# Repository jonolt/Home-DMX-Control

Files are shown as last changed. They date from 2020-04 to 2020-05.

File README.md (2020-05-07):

# Home DMC Controll - DONT USE!
**Dont use the data in this repository. Board and Software are not well designed.**

Improved Project was moved to 2 seperate repositories:
- [Home-DMX-Board](https://github.com/jonolt/Home-DMX-Board)
- [Home-DMX-Firmaware](https://github.com/jonolt/Home-DMX-Firmaware)

is a simple arduino based DMX controller to controll led lights installed in your home to be used with DMX controllers and relais.

## Idea

The selection for the lighting scene in daily use should be as simple as possible. Therefore exactly two push buttons are used to move up and down in a list of lighting scenes. Since I am not a fan of idle transformers, a conventional light switch is used in my application to switch the whole system on and off. In the same way a corresponding scene could be set.

The individual scenes should be adjustable directly on the controller without additional hardware. The input of the scenes works like on lighting control desks without motor faders via potentiometer and buttons. To make the firmware easy (without programmer and co) and maintainable by everyone, an Arduino was used, because it has a USB converter and the IDE is easy to use and install.

## End User Usage

### Everyay Usage

Use the two buttons (connecte do SW2 and SW3 on pcb) to change sceene, by going up and down an scene list.

### Configuration

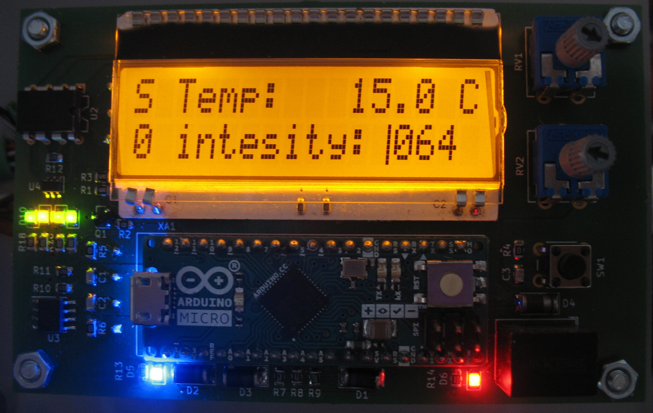
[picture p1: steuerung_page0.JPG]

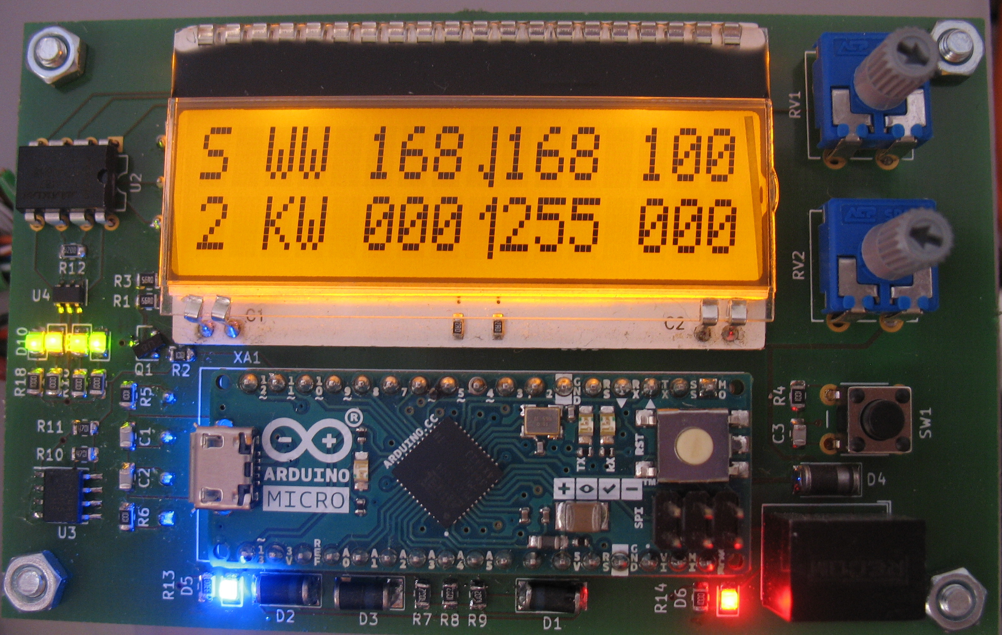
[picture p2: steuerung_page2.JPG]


Exact User Interface depends on the project specific arduino programm. The brigness values are set with two analog potis (one for each line). They work like in Ligthning Cosoles. A arrow up/down means the current poti value is below/above the software value. Chhanfing the poti value will not change the software value until bot values where matched once. This is shown when only a pipe is displayed.

#### Page 0

It is used to adjust the brightness of the display and to show the temperature measured by the I2C temperature sensor.

#### Page X (1, ..., 9)

Each page stores one light scene. In my project I have 3 zones of WW/CW LED stripes which should be switched independently. The zones are divided into columns. With SW1 a column can be selected and with RV1 and RV2 the brightness can be adjusted. To switch pages SW2 and SW3 are used which are not on the board. 

## Hard- and Software

### Hardware

Because I want to see if my hardware is running I have a power LED (D4) and a status LED (D5), which is switched on and off in my loop. This may cost an I/O pin, but you can always see if the firmware is running properly.

The MAX481 (U2) is a transceiver for RS-485 and RS-422 communication based on DMX. It uses the TX and RX pins of the arduino. For a visual control of the DMX communication 2x2 (overkill) leds are connected via buffer (U4).

The display is controlled serially via the library provided by the manufacturer.

Since only one interrupt is available when using IC2, all three switches are connected to it via diodes (D1, D2, D3) and the pressed switch is determined in the ISR. The switches are already hardware debaunced.

The I2C temperature sensor can be used for an emergency shutdown, or as I use it, just to see how warm it is in the chamber with the transformers (I trust the thermal protection of the power supplies).

### Software

The scenes and the current page and current column are stored in the EPPROM. Each page/scene has in the current implementation 10 8-bit registers to store DMX values. These can be accessed by adding the number of the register to the start address of the page, where the start address depends on the current page.

The Main Loop consists of 4 parts

1. Check whether a switch has been pressed and do according action
2. Check whether the potentiometer value has changed and whether the value must be adopted and update the display
3. Write DMX values
4. Toogle status LED

Code is more or less self explaining (sorry for the a bit cryptic math logic for pages). Be aware of the pointers in the trace method.

## Project Example

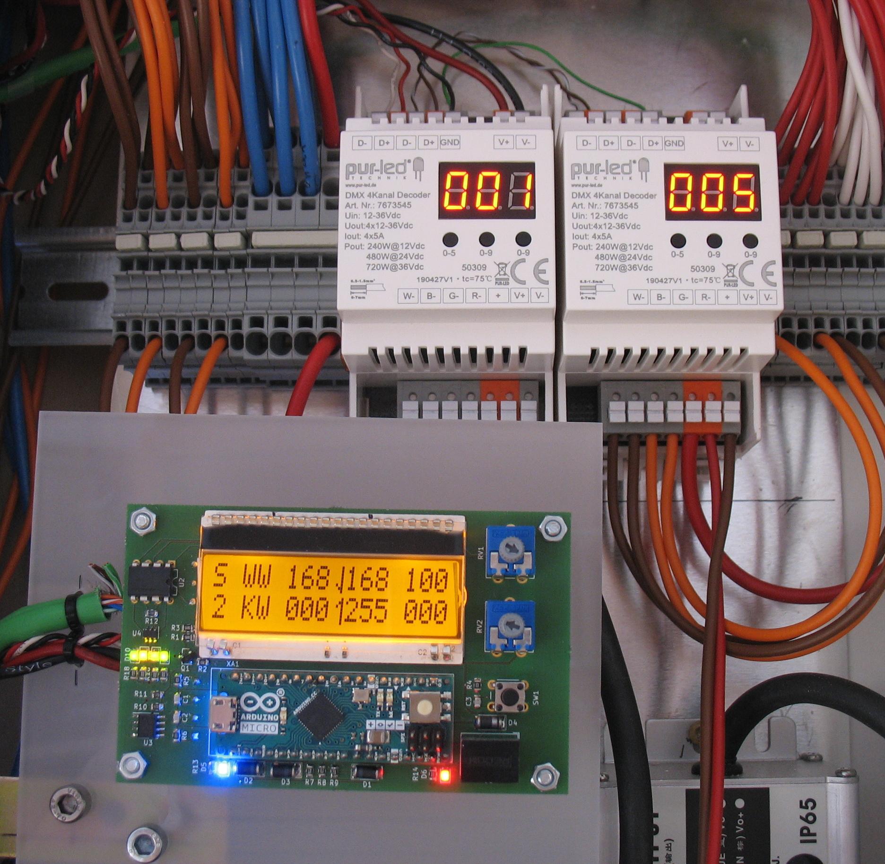
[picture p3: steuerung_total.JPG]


## Licence

See subfolders for indiviadual licences for each part of this project.

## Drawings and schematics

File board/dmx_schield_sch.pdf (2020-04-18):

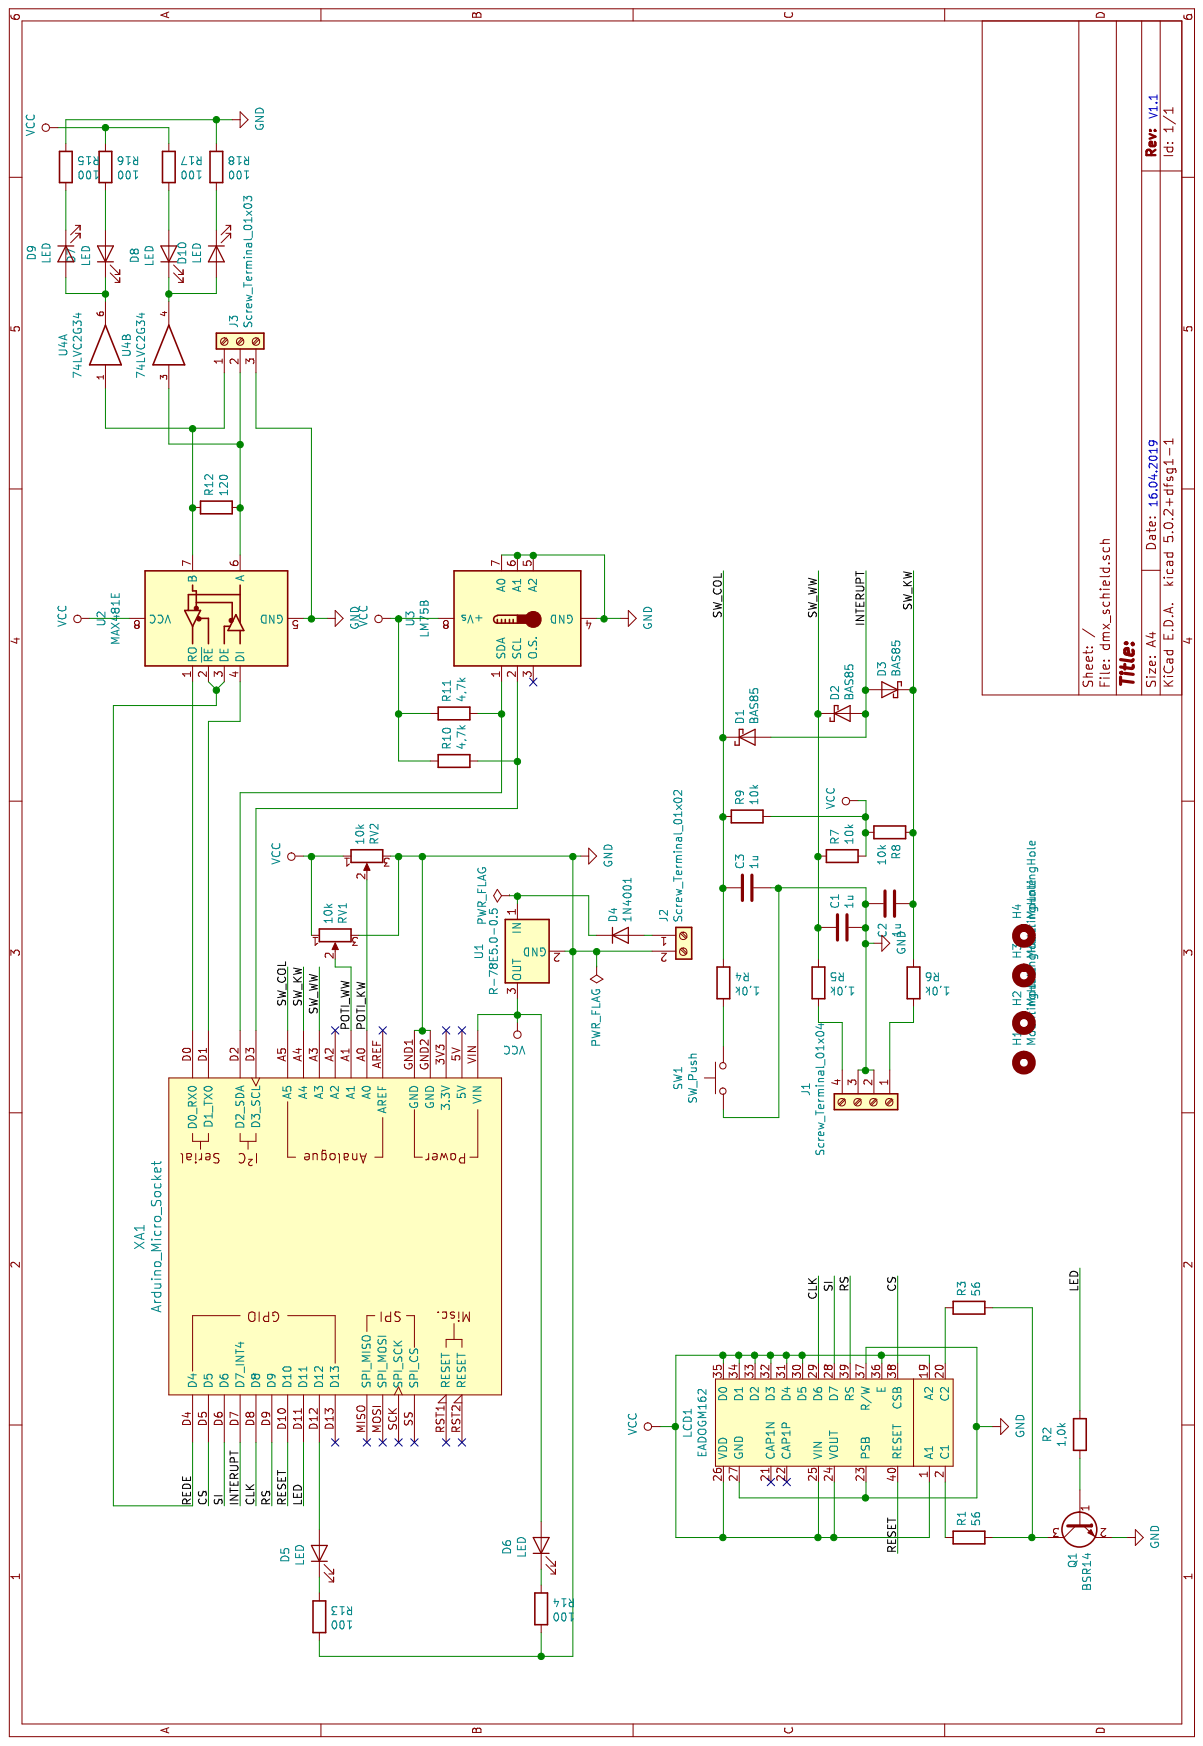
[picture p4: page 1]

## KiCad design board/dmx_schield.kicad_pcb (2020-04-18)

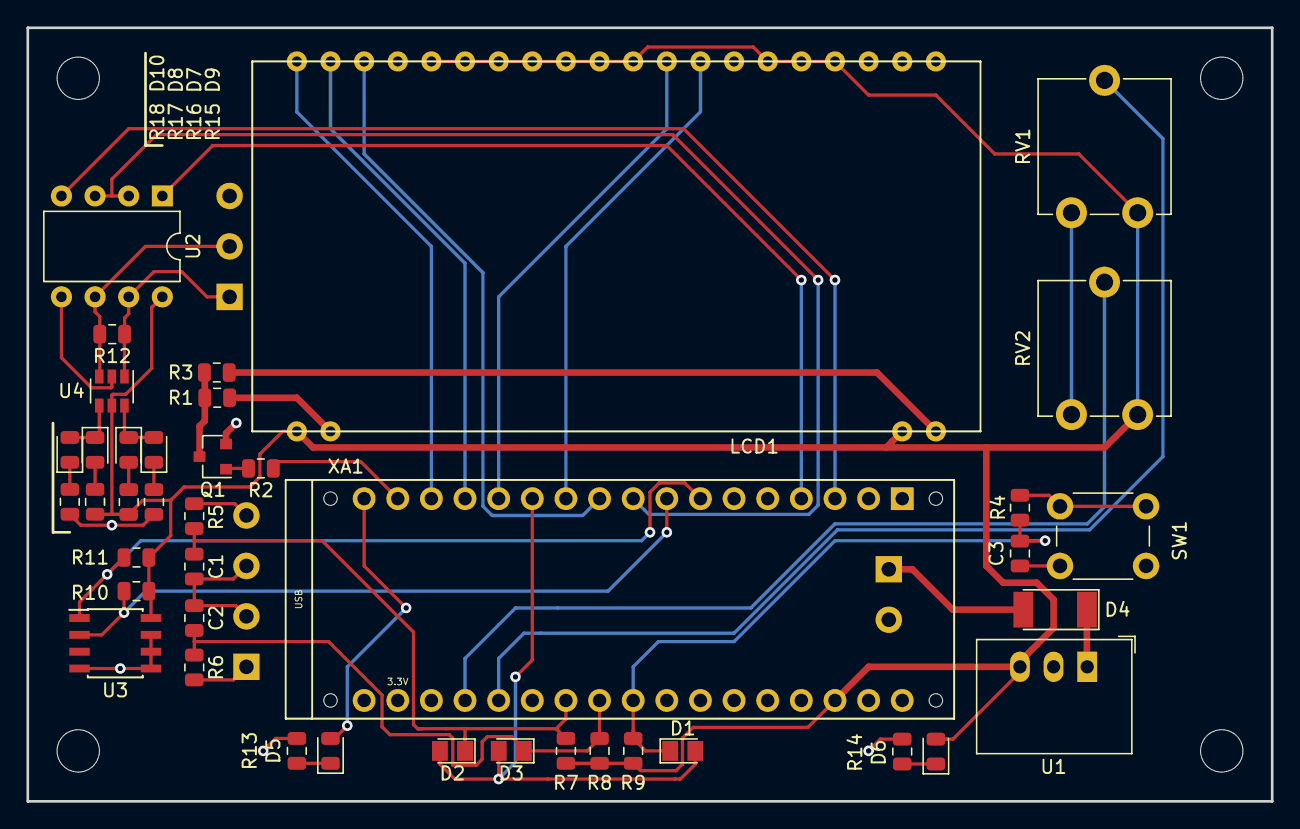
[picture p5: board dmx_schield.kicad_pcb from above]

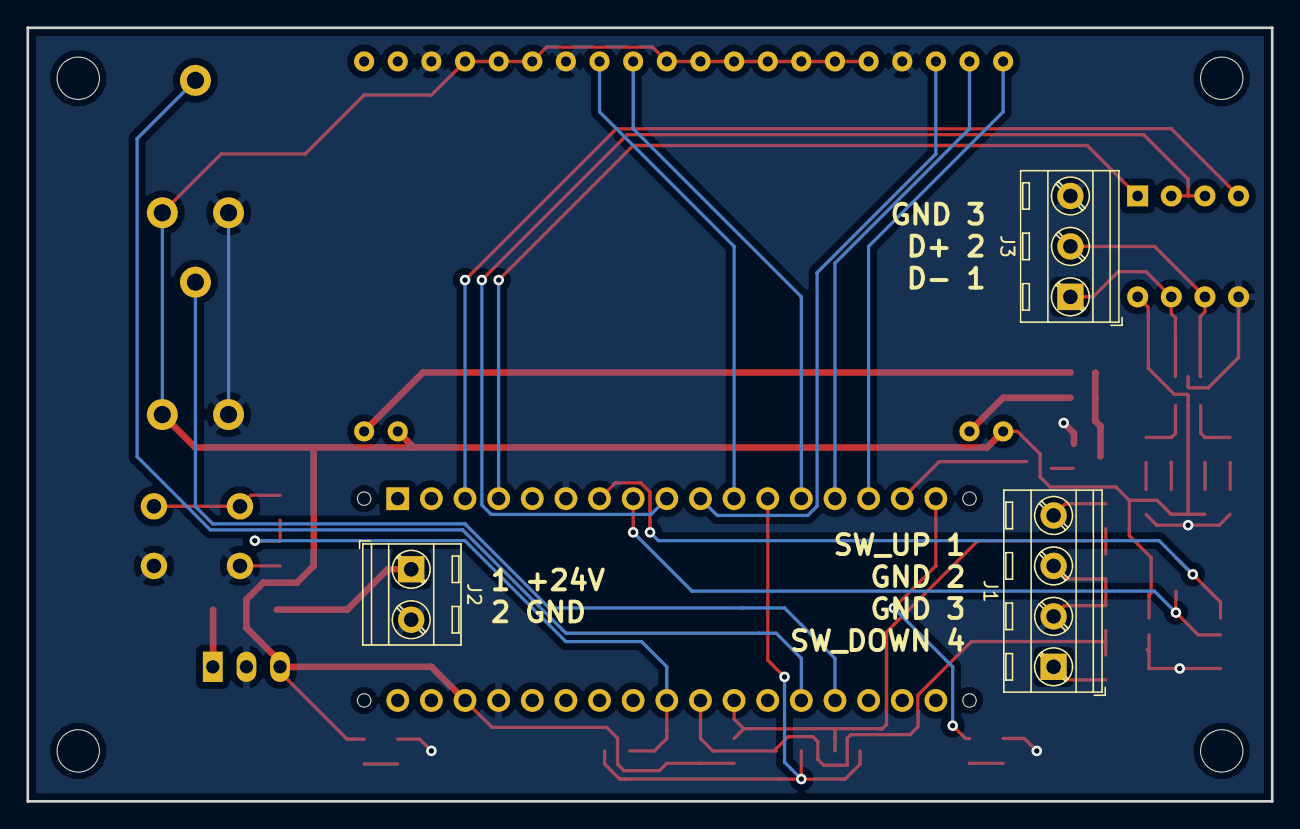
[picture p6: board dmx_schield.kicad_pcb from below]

Board: 2 copper layers, 94.0 x 58.4 mm, 48 parts (3 on the bottom side), 39 nets.

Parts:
C1, C2, C3: 1u; C_0805_2012Metric
D1, D2, D3: BAS85; D_MicroMELF
D4: 1N4001; D_MELF
D5, D6, D7, D8, D9, D10: LED; LED_0805_2012Metric
H1, H2, H3, H4: MountingHole; MountingHole_3.2mm_M3_DIN965
J1: Screw_Terminal_01x04; TerminalBlock_MetzConnect_Type086_RT03404HBLC_1x04_P3.81mm_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
J2: Screw_Terminal_01x02; TerminalBlock_MetzConnect_Type086_RT03402HBLC_1x02_P3.81mm_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
J3: Screw_Terminal_01x03; TerminalBlock_MetzConnect_Type086_RT03403HBLC_1x03_P3.81mm_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
LCD1: EADOGM162; EA DOGM 162
Q1: BSR14; SOT-23
R1, R3: 56; R_0805_2012Metric
R2, R4, R5, R6: 1,0k; R_0805_2012Metric
R7, R8, R9: 10k; R_0805_2012Metric
R10, R11: 4,7k; R_0805_2012Metric
R12: 120; R_0805_2012Metric
R13, R14, R15, R16, R17, R18: 100; R_0805_2012Metric
RV1, RV2: 10k; Potentiometer_ACP_CA9-V10_Vertical
SW1: SW_Push; SW_PUSH_6mm_H5mm
U1: R-78E5.0-0.5; Converter_DCDC_RECOM_R-78E-0.5_THT
U2: MAX481E; DIP-8_W7.62mm
U3: LM75B; SOIC-8_3.9x4.9mm_P1.27mm
U4: 74LVC2G34; SOT-23-6
XA1: Arduino_Micro_Socket

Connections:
/CLK: LCD1.29, XA1.D8
/CS: LCD1.38, XA1.D5
/INTERUPT: D1.2, D2.2, D3.2, XA1.D7
/LED: R2.1, XA1.D11
/POTI_KW: RV2.2, XA1.A0
/POTI_WW: RV1.2, XA1.A1
/REDE: U2.2, U2.3, XA1.D4
/RESET: LCD1.40, XA1.D10
/RS: LCD1.39, XA1.D9
/SI: LCD1.28, XA1.D6
/SW_COL: C3.1, D1.1, R4.1, R9.1, XA1.A5
/SW_KW: C2.2, D3.1, R6.1, R8.1, XA1.A4
/SW_WW: C1.1, D2.1, R5.1, R7.1, XA1.A3
GND: C1.2, C2.1, C3.2, J1.2, J1.3, J2.2, J3.3, LCD1.23, LCD1.27, LCD1.37, Q1.2, R13.2, R14.2, R15.1, R18.1, RV1.3, RV2.3, SW1.1, U1.2, U2.5, U3.4, U3.5, U3.6, U3.7, U4.2, XA1.GND1, XA1.GND2
unnamed: D4.1, U1.1
unnamed: D4.2, J2.1
unnamed: D5.1, R13.1
unnamed: D5.2, XA1.D12
unnamed: D6.1, R14.1
unnamed: D7.1, D9.2, U4.6
unnamed: D7.2, R16.2
unnamed: D8.2, R17.2
unnamed: D9.1, R15.2
unnamed: D10.1, R18.2
unnamed: D8.1, D10.2, U4.4
unnamed: J1.1, R6.2
unnamed: J1.4, R5.2
unnamed: J3.1, R12.1, U2.7, U4.1
unnamed: J3.2, R12.2, U2.6, U4.3
unnamed: LCD1.2, R1.1
unnamed: LCD1.20, R3.1
unnamed: Q1.1, R2.2
unnamed: Q1.3, R1.2, R3.2
unnamed: R4.2, SW1.2
unnamed: R10.2, U3.2, XA1.D3
unnamed: R11.2, U3.1, XA1.D2
unnamed: U2.1, XA1.D0
unnamed: U2.4, XA1.D1
VCC: D6.2, LCD1.1, LCD1.19, LCD1.24, LCD1.25, LCD1.26, LCD1.30, LCD1.31, LCD1.32, LCD1.33, LCD1.34, LCD1.35, LCD1.36, R7.2, R8.2, R9.2, R10.1, R11.1, R16.1, R17.1, RV1.1, RV2.1, U1.3, U2.8, U3.8, U4.5, XA1.VIN

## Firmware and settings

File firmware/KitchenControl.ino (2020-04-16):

/*
 * Copyright (C) 2019, 2020 Johannes N.
 * 
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
 * You should have received a copy of the GNU General Public License
 * along with this program.  If not, see <https://www.gnu.org/licenses/>.
 */

#include <Arduino.h>
#include <SPI.h>
#include <EEPROM.h>
#include <DMXSerial.h>
#include <Temperature_LM75_Derived.h>
#include "dogm_7036.h"

#define LM75_ADDRESS 0x48

#define PIN_BACKLIGHT 11
#define PIN_LED_STATUS 12
#define PIN_ARDUINO_LED 13
#define PIN_POTI_KW A0
#define PIN_POTI_WW A1
#define PIN_INTERUPT 7
#define PIN_SW_UP A3
#define PIN_SW_DOWN A4
#define PIN_SW_COL A5

#define PIN_R232_REDE 4

#define EPPROM_BACKLIGHT 1
#define EEPROM_PAGE 0
#define EPROME_COL 2


//Display
dogm_7036 DOG;
byte DOG_ARROW_POS[] = {5, 9, 13};
byte arrow_none[] = {0x01, 0x01, 0x01, 0x01, 0x01, 0x01, 0x01, 0x01};
byte arrow_up[] = {0x01, 0x03, 0x05, 0x01, 0x01, 0x01, 0x01, 0x01};
byte arrow_down[] = {0x01, 0x01, 0x01, 0x01, 0x01, 0x05, 0x03, 0x01};

//Aquire Value
bool trace_ww = false;
bool trace_kw = false;
bool trace_start = false;
volatile bool isr_triggered = false;
volatile bool isr_state_sw_up = true;
volatile bool isr_state_sw_down = true;
volatile bool isr_state_sw_col= true;


//Others
bool status_led = true;
Generic_LM75 temperature(LM75_ADDRESS);


//Function
void writeDMX();
void set_toogle_status_led();
void trace(byte addr, byte poti_val, bool trace);
void isr();
byte get_addr_start();
byte get_poti_ww_value();
byte get_poti_kw_value();
byte get_poti_value(int pin);
void set_backlight();


void setup() {

  //Setup Display
  DOG.initialize(5, 6, 8, 9, 10, 1, DOGM162); //byte p_cs, byte p_si, byte p_clk, byte p_rs, byte p_res, boolean sup_5V, byte lines
  DOG.displ_onoff(true);
  DOG.cursor_onoff(false);
  DOG.define_char(0, arrow_none);
  DOG.define_char(1, arrow_up);
  DOG.define_char(2, arrow_down);

  //Setup Pins
  pinMode(PIN_BACKLIGHT, OUTPUT);
  digitalWrite(PIN_BACKLIGHT, HIGH);
  pinMode(PIN_LED_STATUS, OUTPUT);
  digitalWrite(PIN_LED_STATUS, HIGH);
  pinMode(PIN_R232_REDE, OUTPUT);
  digitalWrite(PIN_R232_REDE, HIGH);
  pinMode(PIN_SW_COL, INPUT);
  pinMode(PIN_SW_UP, INPUT);
  pinMode(PIN_SW_DOWN, INPUT);
  pinMode(PIN_INTERUPT, INPUT);
  pinMode(PIN_INTERUPT, INPUT_PULLUP);
  attachInterrupt(digitalPinToInterrupt(PIN_INTERUPT), isr, FALLING);

  //Setup EPPROM
  if (EEPROM.read(EEPROM_PAGE) > 9) {
    EEPROM.write(EEPROM_PAGE, 0);
  }
  if (EEPROM.read(EPROME_COL) > 2) {
    EEPROM.write(EPROME_COL, 0);
  }
  EEPROM.write(100, 0);
  EEPROM.write(101, 0);
  EEPROM.write(102, 0);
  EEPROM.write(103, 0);
  EEPROM.write(104, 0);
  EEPROM.write(105, 0);

  //Setup Communiication (DMX, Serial)
  DMXSerial.init(DMXController);
  Wire.begin();

}


void loop() {
  if(isr_triggered){
    delay(50);
    handle_isr();
  } 
  set_backlight();
  if (EEPROM.read(EEPROM_PAGE) != 0) {
    digitalWrite(PIN_ARDUINO_LED, LOW);
    int addr = get_addr_start();
    String strW = "S WW";
    String strK = String(EEPROM.read(EEPROM_PAGE));
    strK.concat(" KW");
    for (int i = 0; i < 3; i++) {
      char buf[3];
      sprintf(buf, " %03d", EEPROM.read(addr + 2 * i));
      strW.concat(buf);
      sprintf(buf, " %03d", EEPROM.read(addr + 2 * i + 1));
      strK.concat(buf);
    }
    DOG.position(1, 1);
    DOG.string(strW.c_str());
    DOG.position(1, 2);
    DOG.string(strK.c_str());
    byte col = EEPROM.read(EPROME_COL);
    DOG.position(DOG_ARROW_POS[col], 1);
    trace(addr + 2 * col, get_poti_ww_value(), &trace_ww);
    DOG.position(DOG_ARROW_POS[col], 2);
    trace(addr + 2 * col + 1, get_poti_kw_value(), &trace_kw);
    delay(100);
  }
  else
  {
    digitalWrite(PIN_ARDUINO_LED, HIGH);
    DOG.position(1, 1);
    DOG.string("S Temp:        C");
    DOG.position(11, 1);
    DOG.string(String(temperature.readTemperatureC(), 1).c_str());
    DOG.position(1, 2);
    DOG.string("0 intesity:");
    char buf[3];
    sprintf(buf, " %03d   ", EEPROM.read(EPPROM_BACKLIGHT));
    DOG.string(buf);
    DOG.position(12, 2);
    trace(EPPROM_BACKLIGHT, get_poti_kw_value(), &trace_start);
    delay(50);
  }
  writeDMX();
  set_toogle_status_led();
}

void writeDMX() {
  //send values from EPPROM to dimmer
  int addr = get_addr_start();
  //RegalUnten
  DMXSerial.write(1, EEPROM.read(addr + 0));
  DMXSerial.write(2, EEPROM.read(addr + 1));
  //RegalOben
  DMXSerial.write(3, EEPROM.read(addr + 2));
  DMXSerial.write(4, EEPROM.read(addr + 3));
  //Glasswand
  DMXSerial.write(5, EEPROM.read(addr + 4));
  DMXSerial.write(6, EEPROM.read(addr + 4));
  DMXSerial.write(7, EEPROM.read(addr + 5));
  DMXSerial.write(8, EEPROM.read(addr + 5));
}

void set_toogle_status_led() {
  //Toogle Statu LED (blinking)
  if (status_led) {
    status_led = false;
  } else {
    status_led = true;
  }
  digitalWrite(PIN_LED_STATUS, status_led);
}


void trace(byte addr, byte poti_val, bool* trace) {
  //compare register value and poti value, writes poti value into
  //EEPROMafter being eqaul for the first time
  if (*trace) {
    EEPROM.write(addr, poti_val);
    DOG.ascii(0);
  }
  else
  {
    byte val_ist = EEPROM.read(addr);
    if (poti_val >= val_ist - 2 && poti_val <= val_ist + 2) {
      *trace = true;
    } else if (poti_val < val_ist) {
      DOG.ascii(1);
    } else {
      DOG.ascii(2);
    }
  }
}

void isr(){
  isr_triggered = true;
  isr_state_sw_up   = digitalRead(PIN_SW_UP);
  isr_state_sw_down = digitalRead(PIN_SW_DOWN);
  isr_state_sw_col  = digitalRead(PIN_SW_COL);
}

void handle_isr() {
  //process all key pressses. Changes page or column.
  //detachInterrupt(digitalPinToInterrupt(PIN_INTERUPT));
  delayMicroseconds(20000);
  if (!isr_state_sw_col) {
    byte col = EEPROM.read(EPROME_COL);
    col++;
    if (col > 2) {
      col = 0;
    }
    EEPROM.write(EPROME_COL, col);
  } else {
    int page = EEPROM.read(EEPROM_PAGE);
    if (!isr_state_sw_up) {
      page++;
    } else if (!isr_state_sw_down) {
      page--;
    }
    if (page > 9) {
      page = 0;
    }
    if (page < 0) {
      page = 9;
    }
    EEPROM.write(EEPROM_PAGE, page);
  }
  trace_ww = false;
  trace_kw = false;
  trace_start = false;
  isr_triggered = false;
  //delay(100);
  //attachInterrupt(digitalPinToInterrupt(PIN_INTERUPT), isr, FALLING);
}

byte get_addr_start() {
  //returns start epprom address for values of current page
  return EEPROM.read(EEPROM_PAGE) * 10 + 100;
}

byte get_poti_ww_value() {
  //returns a 8bit value for the ww (RV1) poti
  return get_poti_value(PIN_POTI_WW);
}

byte get_poti_kw_value() {
  //returns a 8bit value for the kw (RV2) poti
  return get_poti_value(PIN_POTI_KW);
}

inline byte get_poti_value(int pin) {
  //returns a 8bit value for the poti
  return analogRead(pin) / 4;
}

void set_backlight() {
  analogWrite(PIN_BACKLIGHT, EEPROM.read(EPPROM_BACKLIGHT));
}

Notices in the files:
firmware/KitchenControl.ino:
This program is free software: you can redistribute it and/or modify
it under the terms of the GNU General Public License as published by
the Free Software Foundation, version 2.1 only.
